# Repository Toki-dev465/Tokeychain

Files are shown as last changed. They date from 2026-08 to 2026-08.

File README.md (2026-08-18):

# Introduction
I built this project as a fun way to learn more about PCB, CAD and firmware design. I spent quite a lot of time on it and learned a lot especially about CAD modelling. I hope to show it off by hooking it up to my keys and other accessories.

# How it works
The Xiao ESP32-S3 reads tilt from the ADXL345 accelerometer. This is used to create interactive animations displayed on the OLED. As of right now, there is only one "game", the ball game. As you tilt the device the ball starts speeding up in that direction and slows down over time from "friction." The ball also bounces off the edge, which is displayed as a white box. The device will support more of these interactive animations and the animations will be cycled by tap detection on the accelerometer module. This version of the Xiao supports a rechargeable battery with an on-board charging module, which this device will utilize.

# Assembly instructions
1. Insert OLED: Place the OLED in the rectangular cutout on the case.
2. Stack components: Place the PCB and the battery on top of the OLED.
3. Close case: Snap back cover onto the case until it securely clicks in place. 

# Firmware & Flashing

* **ino (arduino) file:** [ball_game.ino](Firmware/ball_game.ino)

1. Install Arduino IDE
2. Add ESP 32 board support: Click on file, preferences, then paste this into the additional board managers URL (https://raw.githubusercontent.com/espressif/arduino-esp32/gh-pages/package_esp32_index.json)
3. Select tools, board, then board manager. Search ESP 32 and install it
4. Select tools, board, esp32, then select Xiao ESP-32-S3 and plug in the device.
5. Hit sketch, then upload 

# Challenges
All went quite smoothly except for the CAD modelling part. I used Fusion only once and that was by following a tutorial. Therefore, this project gave me a massive headache! I had lots of trouble just doing the most basic and minute things such as creating a sketch, projecting onto a sketch, etc. However, due to the immense amount of time I spent, I learned a lot regarding the basics of Fusion and spending so much time on it just made completing the final design more rewarding. I am very proud of how it turned out. 

# PCB design
The schematic and PCB were made using the open-source software KiCad. I made sure to use global net variables for the schematic because otherwise, I would be left with incomprehensible messy wiring. The PCB uses a two-layer system. The top layer (F.Cu) is used for routing traces, whereas the bottom layer (B.Cu) is used for grounding using copper fill zones. I made sure to make the power traces 0.5mm in thickness as recommended by professionals in the industry.

| Schematic | PCB |
|---|-----|
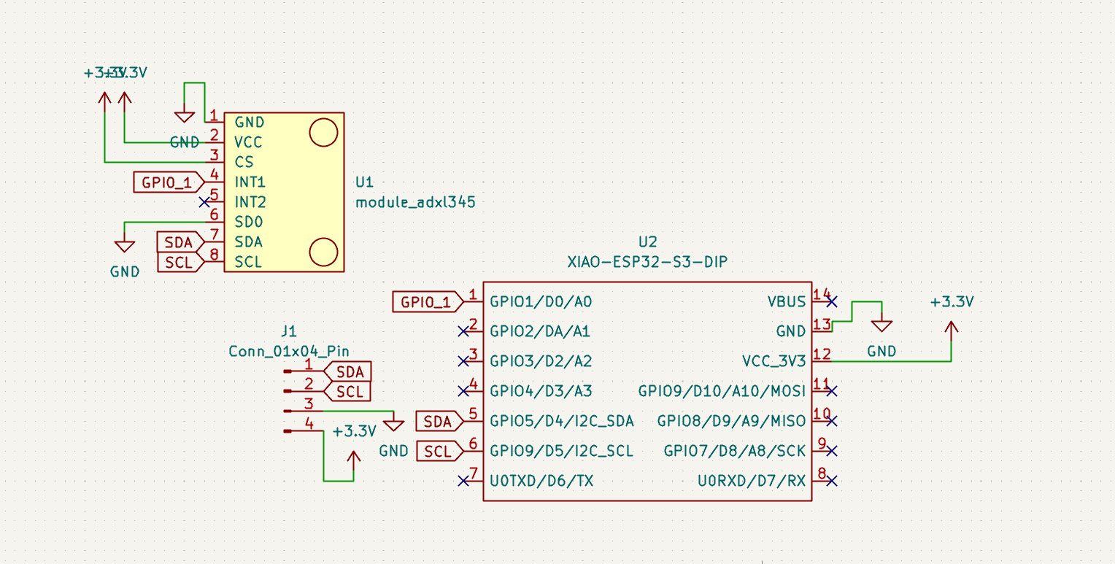
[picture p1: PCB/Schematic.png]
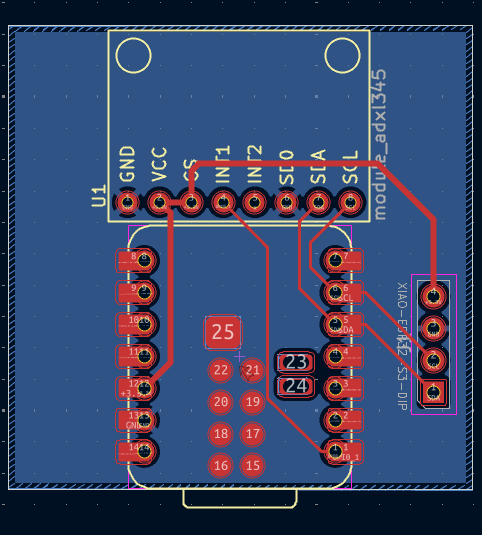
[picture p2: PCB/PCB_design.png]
|  |  |

### PCB and Schematic files

* **Project:** [Tokeychain.kicad_pro](PCB/Tokeychain.kicad_pro)
* **PCB:** [Tokeychain.kicad_pcb](PCB/Tokeychain.kicad_pcb)
* **Schematic:** [Tokeychain.kicad_sch](PCB/Tokeychain.kicad_sch)
* **Gerbers:** [Tokeychain_Gerbers.zip](PCB/Tokeychain_Gerbers.zip)

# CAD design
The CAD components were built using AutoDesk Fusion software. The components are all inside a 38x50x20 mm 3D-printed case with a key loop at the top and a USB-C cutout at the bottom. The back is covered using a snap-fit cover.

| Fusion Snapshot |
|------------------|
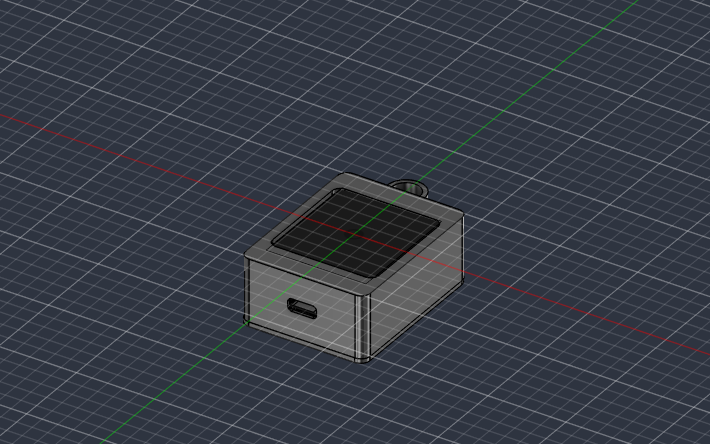
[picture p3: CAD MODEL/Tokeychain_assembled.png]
|  |

### CAD & Print Files

* **Preview:** [Tokeychain_assembled.png](CAD%20MODEL/Tokeychain_assembled.png)
* **3D Model:** [Tokeychain.stl](CAD%20MODEL/Tokeychain.stl)
* **Source File:** [Tokeychain_assembled.f3z](CAD%20MODEL/Tokeychain_assembled.f3z)
* **Step file:** [Tokeychain_assembled.step](CAD%20MODEL/Tokeychain_assembled.step)

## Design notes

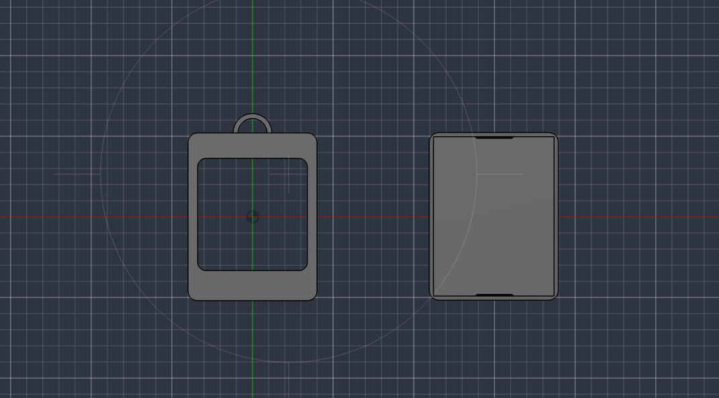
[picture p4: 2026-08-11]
CAD MODEL/Screenshot 2026-08-09 232611.png

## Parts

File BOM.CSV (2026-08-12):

Quantity | Item | Price(excl tax & ship) | Link
1 | XIAO ESP32-S3 | $7.49 | https://www.digikey.ca/en/products/detail/seeed-technology-co-ltd/113991114/19285530
1 | ADXL345 module | $2.55 | https://www.aliexpress.com/item/1005010198382356.html
1 | SH1107 1.5 inch I2C OLED display | $7.59 | https://www.aliexpress.com/item/1005009890032032.html
1 | 502030 Battery 3.7V Lipo 250mAh | $5.63 | https://www.aliexpress.com/item/1005006584143607.html

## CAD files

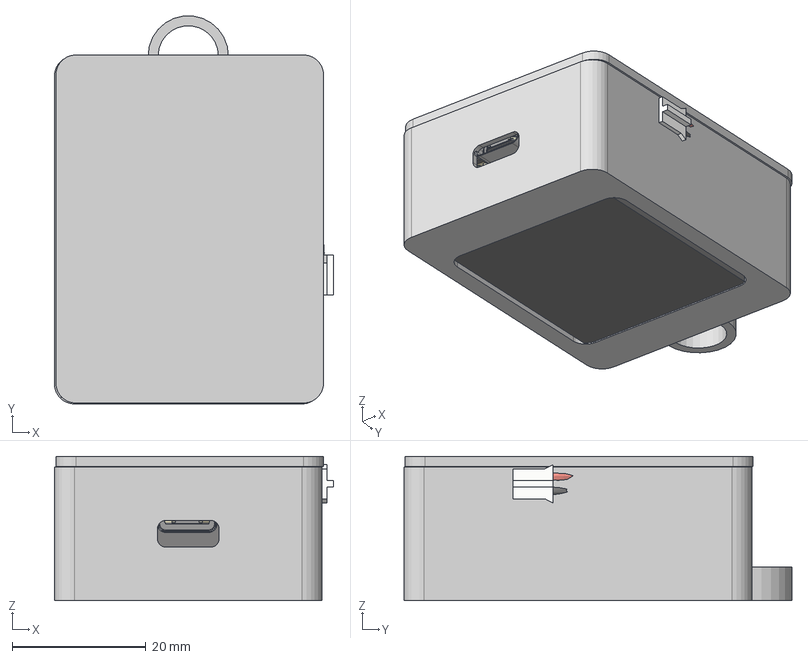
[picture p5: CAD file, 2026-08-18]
CAD MODEL/Tokeychain_assembled.step
41.7 x 58.0 x 21.6 mm

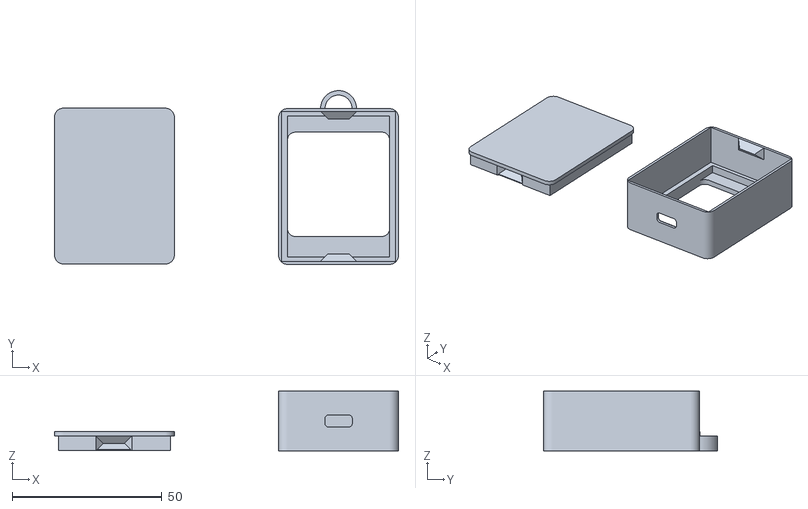
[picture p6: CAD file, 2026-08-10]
CAD MODEL/Click to view case + cover.stl
114.8 x 58.0 x 20.0

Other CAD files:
CAD MODEL/Case and cover.step
CAD MODEL/Tokeychain_assembled.f3z
CAD MODEL/Tokeychain_assembled.stl

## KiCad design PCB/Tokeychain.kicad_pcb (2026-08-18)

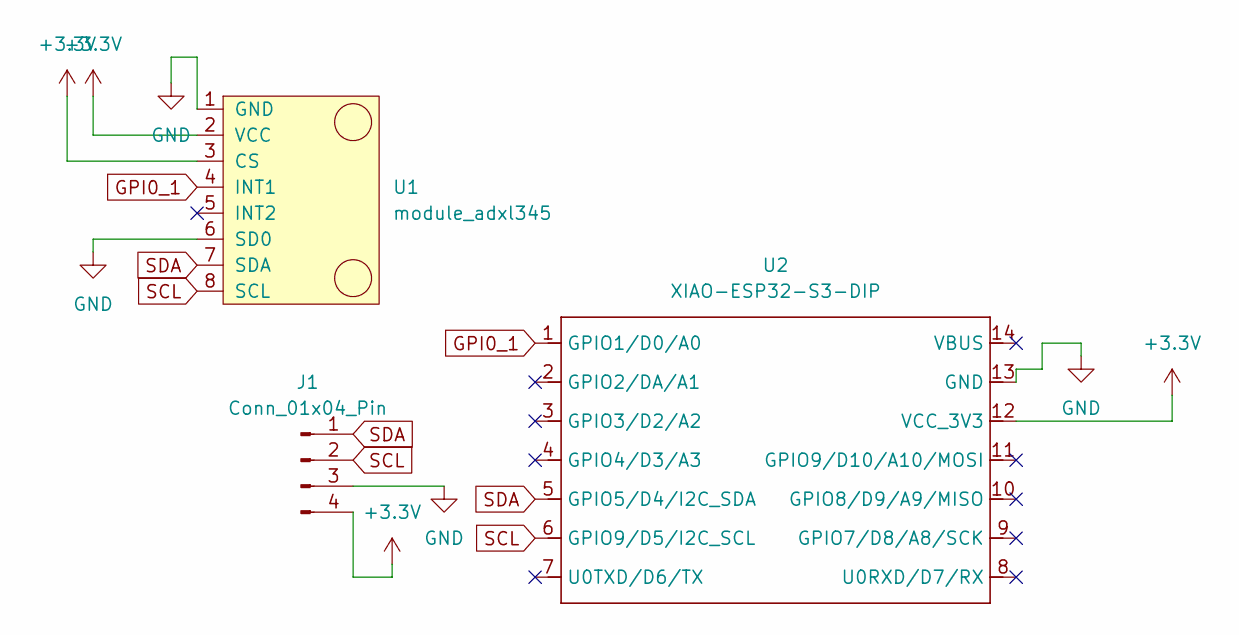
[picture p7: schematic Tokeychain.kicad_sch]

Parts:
J1: Conn_01x04_Pin; OLED_SSD1306_I2C_0.96
U1: module_adxl345
U2: XIAO-ESP32-S3-DIP

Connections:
+3.3V: J1.4, U1.2 (VCC), U1.3 (CS), U2.12 (VCC_3V3)
GND: J1.3, U1.1 (GND), U1.6 (SD0), U2.13 (GND)
GPI0_1: U1.4 (INT1), U2.1 (GPIO1/D0/A0)
SCL: J1.2, U1.8 (SCL), U2.6 (GPIO9/D5/I2C_SCL)
SDA: J1.1, U1.7 (SDA), U2.5 (GPIO5/D4/I2C_SDA)

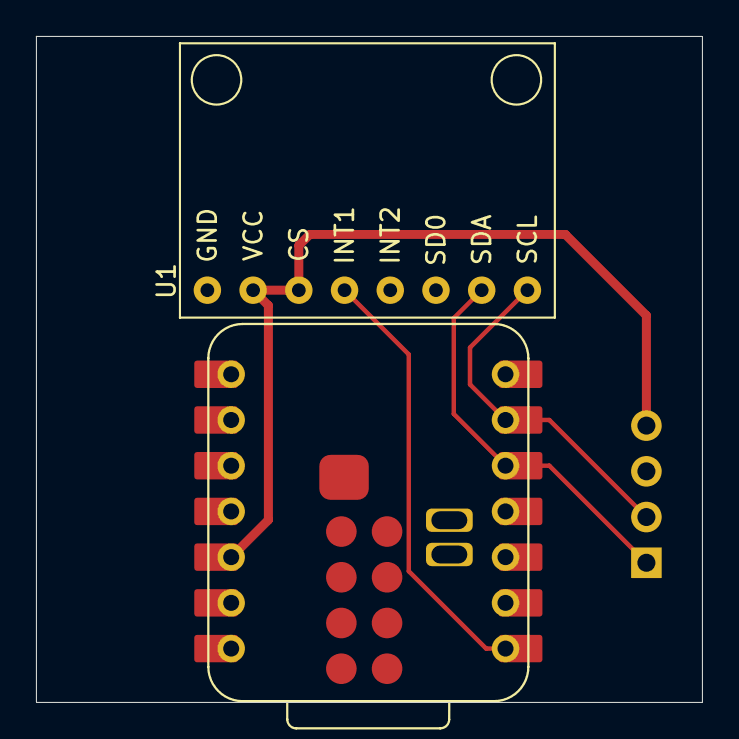
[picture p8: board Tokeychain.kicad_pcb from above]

Board: 2 copper layers, 37.0 x 37.0 mm, 3 parts (0 on the bottom side), 5 nets.

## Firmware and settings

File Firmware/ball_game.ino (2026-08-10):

#include <Wire.h>
#include <Adafruit_GFX.h>
#include <Adafruit_SH110X.h>
#include <Adafruit_Sensor.h>
#include <Adafruit_ADXL345_U.h>

//  Display
#define SCREEN_WIDTH  128
#define SCREEN_HEIGHT 128
#define OLED_RESET    -1
#define OLED_I2C_ADDR 0x3D
Adafruit_SH1107 display(SCREEN_WIDTH, SCREEN_HEIGHT, &Wire, OLED_RESET);

// accelerometer
Adafruit_ADXL345_Unified accel = Adafruit_ADXL345_Unified(12345);

// Axis remap since on PCB, accelerometer is tilted 90 degrees left
#define SWAP_XY      true  // sensor X/Y are swapped
#define TILT_X_SIGN  -1    // flip to +1 if the ball rolls left/right backwards
#define TILT_Y_SIGN   1    // flip to -1 if the ball rolls up/down backwards

// Ball physics 
float ballX = SCREEN_WIDTH  / 2.0;
float ballY = SCREEN_HEIGHT / 2.0;
float velX = 0, velY = 0;

const float BALL_RADIUS = 4.0;
const float MARGIN      = 2.0;   // gap between the arena wall and the screen edge
const float ACCEL_SCALE = 40.0;  // higher = ball reacts to tilt more strongly
const float DAMPING     = 0.985; // rolling friction; closer to 1.0 = less friction
const float RESTITUTION = 0.55;  // bounciness off the walls, 0 = stops, 1 = perfect bounce

unsigned long lastFrame = 0;

void setup() {
  Serial.begin(115200);
  Wire.begin(D4, D5); // SDA = D4, SCL = D5

  if (!display.begin(OLED_I2C_ADDR, true)) {
    Serial.println("SH1107 not found — check wiring/address.");
    while (1) delay(10);
  }
  display.clearDisplay();
  display.display();

  if (!accel.begin()) {
    Serial.println("ADXL345 not found — check wiring.");
    while (1) delay(10);
  }
  accel.setRange(ADXL345_RANGE_4_G);

  lastFrame = millis();
}

void loop() {
  unsigned long now = millis();
  float dt = (now - lastFrame) / 1000.0;
  if (dt <= 0) return;
  if (dt > 0.05) dt = 0.05; // clamp so a stall doesn't fling the ball
  lastFrame = now;

  // Read tilt
  sensors_event_t accelEvent;
  accel.getEvent(&accelEvent);
  float rawX = accelEvent.acceleration.x;
  float rawY = accelEvent.acceleration.y;

  float tiltX, tiltY;
  if (SWAP_XY) {
    tiltX = TILT_X_SIGN * rawY;
    tiltY = TILT_Y_SIGN * rawX;
  } else {
    tiltX = TILT_X_SIGN * rawX;
    tiltY = TILT_Y_SIGN * rawY;
  }

  // Physics
  velX += tiltX * ACCEL_SCALE * dt;
  velY += tiltY * ACCEL_SCALE * dt;
  velX *= DAMPING;
  velY *= DAMPING;
  ballX += velX * dt;
  ballY += velY * dt;

  // Wall collision
  float minX = MARGIN + BALL_RADIUS;
  float maxX = SCREEN_WIDTH  - MARGIN - BALL_RADIUS;
  float minY = MARGIN + BALL_RADIUS;
  float maxY = SCREEN_HEIGHT - MARGIN - BALL_RADIUS;

  if (ballX < minX) { ballX = minX; velX = -velX * RESTITUTION; }
  if (ballX > maxX) { ballX = maxX; velX = -velX * RESTITUTION; }
  if (ballY < minY) { ballY = minY; velY = -velY * RESTITUTION; }
  if (ballY > maxY) { ballY = maxY; velY = -velY * RESTITUTION; }

  // Draw 
  display.clearDisplay();
  display.drawRoundRect((int)MARGIN, (int)MARGIN,
                         SCREEN_WIDTH  - (int)(2 * MARGIN),
                         SCREEN_HEIGHT - (int)(2 * MARGIN),
                         6, SH110X_WHITE);
  display.fillCircle((int)ballX, (int)ballY, (int)BALL_RADIUS, SH110X_WHITE);
  display.display();
}

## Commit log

2026-08-10 Create CAD folder
2026-08-10 Add links to components in README specs
    Updated the Specs/BOM section with links to components.
2026-08-11 Add Bill of Materials (BOM) with items and links
    Added a BOM with quantities, items, and links.
    [BOM.CSV]
2026-08-11 Revise README for clarity and additional sections
    Updated the README to improve clarity and structure. Added sections on how the project works, PCB design, challenges faced, and CAD design.
2026-08-11 Fixed challenges and PCB design order
2026-08-12 Add price column to BOM.CSV
    Updated BOM.CSV to include prices for each item.
    [BOM.CSV]
2026-08-18 Update PCB and Schematic file links in README
2026-08-18 Revise firmware section and add Arduino file link
    Updated the firmware section title and added a link to the Arduino file.
2026-08-18 Add assembly instructions to README
    Added assembly instructions for device setup.
